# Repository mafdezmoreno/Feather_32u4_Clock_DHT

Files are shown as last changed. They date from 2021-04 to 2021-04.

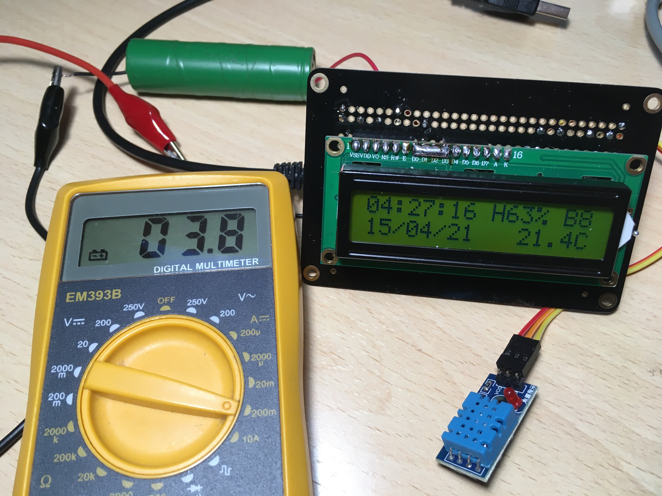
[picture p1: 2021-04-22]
low_power_demo.jpeg

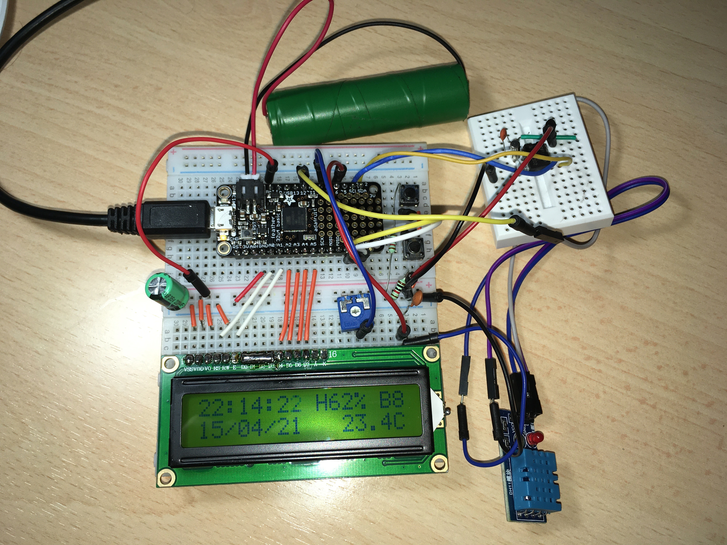
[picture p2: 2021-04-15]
clock_conections.jpeg

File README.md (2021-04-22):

# Feather_32u4_Clock_DHT
 RTC clock with liquid crystal display, humidity and temperature sensor, powered by lithium battery. Developed on a Feather 32u4 basic board.



## Initial Functional Version

Clock connected to RTC PCF8583.

__It is composed of__:

- Liquid crystal display
- Feather 32u4 basic
- Battery
- DHT11 sensor
- PCF8583

__Features__:

- Displays: time, date, battery level, temperature and humidity.
- Allows to change the time by push buttons

https://user-images.githubusercontent.com/59566401/114939320-90d66f80-9e40-11eb-9616-02955f184454.mp4

## New features. Low power consumption

Using the functions provided by the "avr/power.h" library, the average power consumption has been reduced to 3.8 mA. This allows powering the clock with a 3000mA battery for almost 30 days.

The power consumption reduction is achieved by deactivating the power supply to all the peripherals that are not necessary, and activating the necessary peripherals only during the strictly necessary time.

The following image shows the power consumption reduction achieved.

low_power_demo

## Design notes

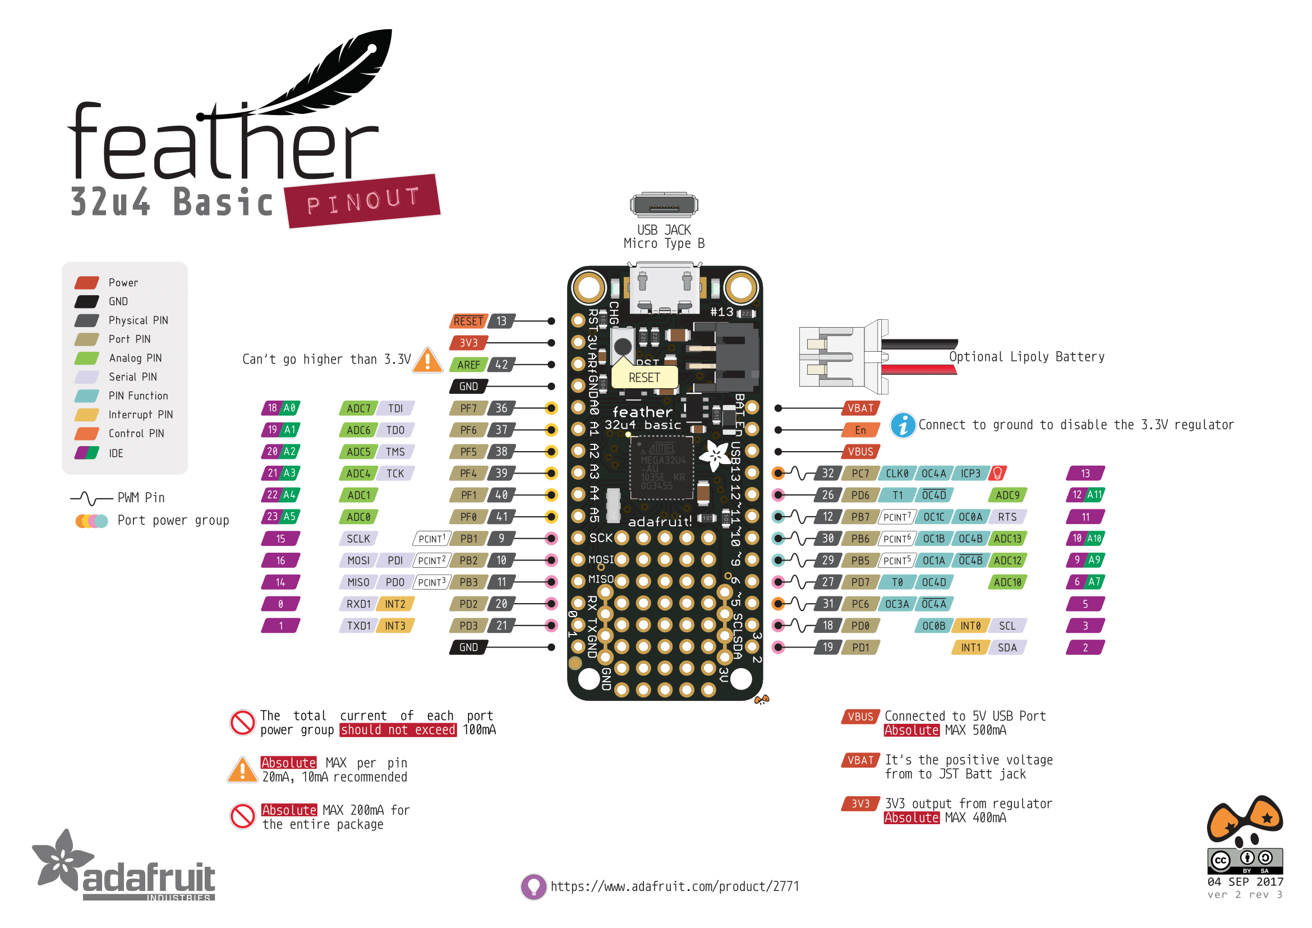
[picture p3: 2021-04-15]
Adafruit_Feather_32u4_Basic_Proto_v2.3-1.png

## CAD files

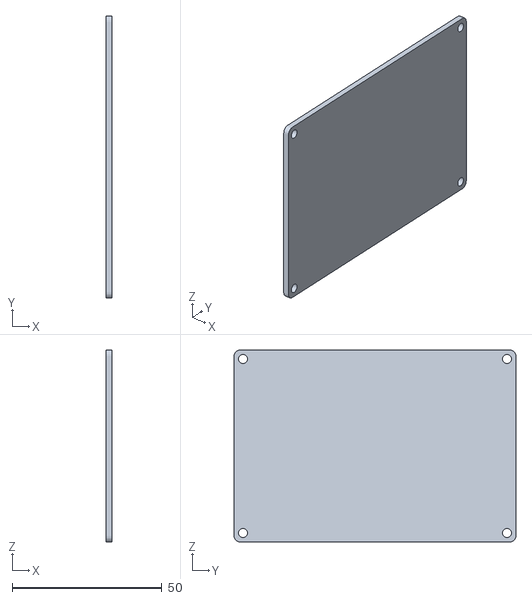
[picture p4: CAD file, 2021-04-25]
3D/PCB.stl
2.00 x 94.0 x 64.0

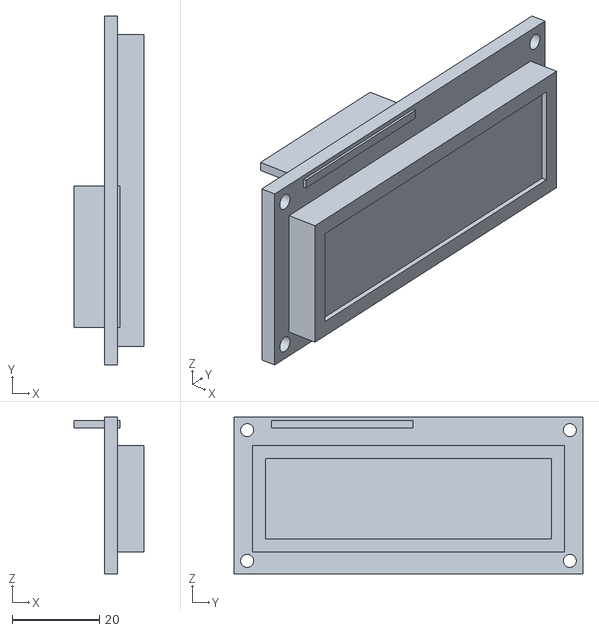
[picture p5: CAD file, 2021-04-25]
3D/LCD.stl
16.0 x 80.0 x 36.0

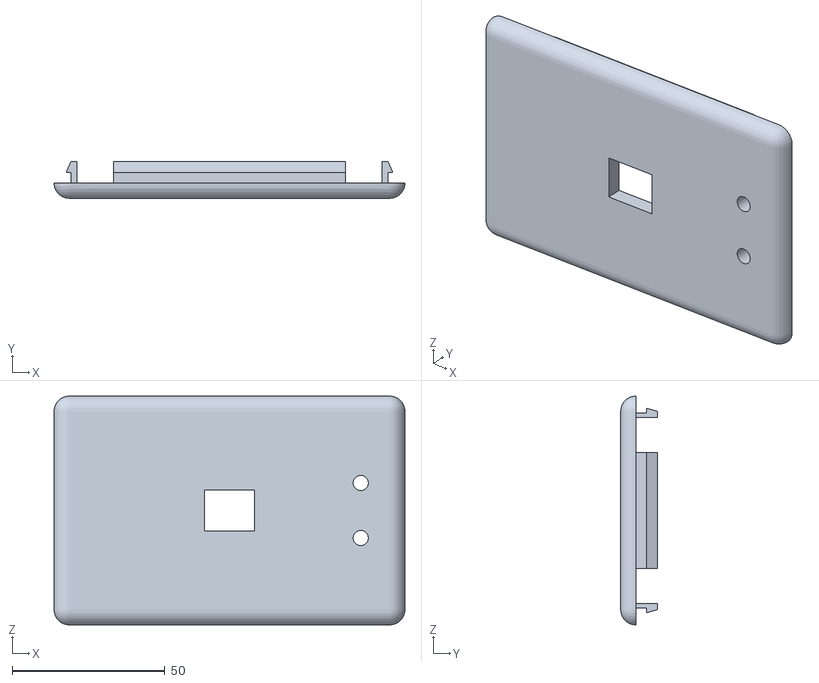
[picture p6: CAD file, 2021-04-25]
3D/Rear_Cover.stl
115.0 x 12.0 x 75.0

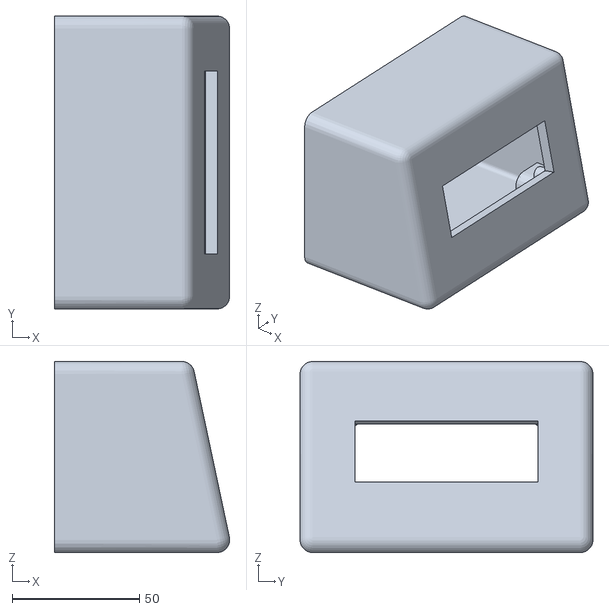
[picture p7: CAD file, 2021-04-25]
3D/Box.stl
68.8 x 115.0 x 75.0

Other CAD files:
3D/Box.prt
3D/Ensamblaje.prt
3D/LCD.prt
3D/PCB.prt
3D/Rear_Cover.prt

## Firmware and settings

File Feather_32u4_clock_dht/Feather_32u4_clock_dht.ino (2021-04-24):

/* Referencias:
https://www.mouser.es/datasheet/2/302/PCF8583-1127587.pdf
http://www.valachnet.cz/lvanek/diy/homebrain/index.html
https://bitbucket.org/xoseperez/pcf8583/src/master/
https://harizanov.com/2013/02/power-saving-techniques-on-the-atmega32u4/
https://www.nongnu.org/avr-libc/user-manual/group__avr__power.html
https://ww1.microchip.com/downloads/en/DeviceDoc/Atmel-7766-8-bit-AVR-ATmega16U4-32U4_Datasheet.pdf
*/
#include "LiquidCrystal.h"
#include "DHT.h"
#include "PCF8583.h"
#include <avr/power.h>

#define DHTPIN 9         // Pin digital
#define DHTTYPE DHT11     // Tipo sensor de humdad y temperatura
#define BAT_LEVEL_PIN A10 // Pin analógico monitorización batería
#define HORA_PIN 0
#define MIN_PIN 1
#define POWER_DHT 6       // Pin alimentación a sensor. Se activa 2 seg cada 30 seg, para ahorrar batería


// Inicialización de la pantalla LCD
const int rs = 19, en = 18, d4 = 20, d5 = 21, d6 = 22, d7 = 23;
LiquidCrystal lcd(rs, en, d4, d5, d6, d7);

// Inicialización de DHT
DHT dht(DHTPIN, DHTTYPE);

// Inicialización de RTC (Dirección I2C)
PCF8583 rtc(0xA0);

//Variables globales
unsigned int ano = 2021;
unsigned int mes = 4;
unsigned int dia = 22;
unsigned int hora = 23;
unsigned int min = 4;
unsigned int seg = 0;
unsigned int activacion_sensor = 243; //para no actualizar constantemente el sensor
                                //Para que me muestre la temp y humedad pronto pongo un valor cerca del valor de reinicio del contador (254)
unsigned int activacion_lect_nivel_bat = 990; //aprox 1000 seg (1000 loops)                               
bool imprimir_fecha = true;

void nivel_bateria();
void temperatura_humedad();
void setup();
void test_rtc(const char * test, byte expected, byte real);
void imprime_hora();
void cambiar_hora();
void imprime_fecha();
void low_power();
void blink_test();

void loop() {
  
  while (1){
    
    imprime_fecha();
    temperatura_humedad();
    nivel_bateria();
    imprime_hora();
    cambiar_hora();
    imprime_fecha();
    delay(998);
  }
}

void setup() {

  // E/S
  pinMode(POWER_DHT, OUTPUT);
  digitalWrite(POWER_DHT, LOW);
  pinMode(HORA_PIN, INPUT);
  pinMode(MIN_PIN, INPUT);

  //Configuración de la pantalla
  lcd.begin(16, 2); 
  lcd.print("Starting...");
  delay(500);
  lcd.setCursor(0, 1);

  // Configuración de RTC. Solo para comprobar correcto conexionado
  //rtc.setTime(0, 0, 0);
  //rtc.setDateTime(seg, min, hora, dia, mes, ano); //Descomentar para poner correctamente la serie
  //test_rtc("sec", 0, rtc.getSecond());

  //Configuración de DHT
  dht.begin();

  // Configuración para ahorrar batería
  low_power();
}

void low_power()
{
  ////////////////////////////////////////////
  //Se parte de un consumo inicial de 12.5mV
  ////////////////////////////////////////////
  delay(10000); //para permitir resetear y cargar nuevo firmware
  // Se desactivan periféricos que no se usan del micro
  power_adc_disable(); //Hace que no funcione la lectura analógica del nivel de batería
  //power_aca_enable(); // Se activa solo temporalmente para leer el nivel de batería
  power_usart1_disable();
  power_usart0_disable();
  power_timer1_disable();  
  power_timer2_disable();
  power_timer3_disable();
  power_spi_disable();
  power_usb_disable();
  //power_twi_disable(); //NO USAR Hace que no funcione la pantalla LCD
  ////////////////////////////////////////////
  // Hasta aquí, se consiguen 11mA de consumo
  ////////////////////////////////////////////
  lcd.clear();
  lcd.print("Setting RC ON"); 
  delay(500);

  // Switch to RC Clock 
  UDINT  &= ~(1 << SUSPI); // UDINT.SUSPI = 0; Usb_ack_suspend
  USBCON |= ( 1 <<FRZCLK); // USBCON.FRZCLK = 1; Usb_freeze_clock
  PLLCSR &= ~(1 << PLLE); // PLLCSR.PLLE = 0; Disable_pll
 
  CLKSEL0 |= (1 << RCE); // CLKSEL0.RCE = 1; Enable_RC_clock()
  while ( (CLKSTA & (1 << RCON)) == 0){}    // while (CLKSTA.RCON != 1);  while (!RC_clock_ready())
  CLKSEL0 &= ~(1 << CLKS);  // CLKSEL0.CLKS = 0; Select_RC_clock()
  CLKSEL0 &= ~(1 << EXTE);  // CLKSEL0.EXTE = 0; Disable_external_clock
  
  lcd.clear();
  lcd.print("RC ON"); 
  delay(1000);

  ////////////////////////////////////////////
  // Hasta aquí, se consiguen 7.8mA de consumo
  ////////////////////////////////////////////

  clock_prescale_set(clock_div_4); // Reduce el consumo hasta 5,6mA, pero no funciona el sensor DHT
                                   // Cambiar a "clock_div_1" cuando se tenga que leer el sensor DHT y justo despues volver a "clock_div_2" para ahorrar energía


  ////////////////////////////////////////////
  // Consumo final conseguido: 
  /////                      5.4mA de consumo con "clock_div_2"
  /////                      3.8mA de consumo con "clock_div_4""
  ////////////////////////////////////////////

  lcd.clear();
  lcd.print("Low Power ON"); 
  delay(1000);
  //blink_test();
  lcd.clear();

}

void cambiar_hora(){
  while (digitalRead(MIN_PIN)){
    
    delay(50);
    if (digitalRead(MIN_PIN)){
        if (++min > 59){
          min = 0;
        }
        rtc.setTime(seg, min, hora);
    }
    imprime_hora();
    delay(400); 
  }

  while (digitalRead(HORA_PIN)){
    delay(50);
    if (digitalRead(HORA_PIN)){
        if (++hora > 23){
          hora = 0;
        }
        rtc.setTime(seg, min, hora);
    }
    imprime_hora();
    delay(400);
  }

}

void imprime_hora(){
    lcd.setCursor(0, 0);
    //Hora
    hora = rtc.getHour();
    if (hora<10){
      lcd.print(0);
    }
    lcd.print(hora);
    lcd.print(":");
    //Minuto
    min = rtc.getMinute();
    if (min<10){
      lcd.print(0);
    }
    lcd.print(min);
    lcd.print(":");
    //Segundo
    seg = rtc.getSecond();
    if (seg<10){
      lcd.print(0);
    }
    lcd.print(seg);

}

void test_rtc(const char * test, byte expected, byte real) {
    lcd.clear();
    lcd.setCursor(0, 1); // segunda fila, posición 0
    if (expected == real) {
        lcd.print("OK");
        lcd.print(real);

    } else {
        lcd.print("KO");
        lcd.print(test);
        delay(500);
        abort();
    }
}
void temperatura_humedad(){

  if (activacion_sensor == 245){
    digitalWrite(POWER_DHT, HIGH);
    clock_prescale_set(clock_div_1);
  }
  else if (activacion_sensor == 250){  
    int h = dht.readHumidity();
    float t = dht.readTemperature();
    digitalWrite(POWER_DHT, LOW);
    lcd.setCursor(11, 1); // segunda fila, posición 11

    // Si la lectura no es correcta, imprime fallo
    if (isnan(h) || isnan(t)) {
      lcd.print("Fallo");
    }
    else{
      //Imprime temperatura
      lcd.print(t,1);
      lcd.print("C");
      
      lcd.setCursor(9, 0);
      lcd.print("H");
      lcd.print(h);
      lcd.print("%");
    }
    activacion_sensor = 0;
    clock_prescale_set(clock_div_4);
  } 
    activacion_sensor ++;
}

void nivel_bateria(){
    
    if (activacion_lect_nivel_bat == 995){
      power_adc_enable();
    }
    else if(activacion_lect_nivel_bat == 1000){
      int bat_level = 0;
      int bat_level_maped = 0;
      bat_level = analogRead(BAT_LEVEL_PIN); //El nivel real está dividido entre 2 
      bat_level_maped = map(bat_level*2, 930, 1240, 0, 9); 
                          //1240 equivale a 4 volt
                          //930 equivale a 3 volt (batería gastada)
      lcd.setCursor(14, 0);
      lcd.print("B");
      lcd.print(bat_level_maped);
      lcd.print(bat_level);
      activacion_lect_nivel_bat = 0;
      power_adc_disable();      
    }
  activacion_lect_nivel_bat++;      
}

void imprime_fecha(){

  if ((hora == 0)&&(min == 0)&&(seg<5)){
    imprimir_fecha = true;
  }

  if (imprimir_fecha){
    lcd.setCursor(0,1);
    int day = rtc.getDay();
    if (day<10){
      lcd.print("0");
    }
    lcd.print(day);
    lcd.print("/");

    int mes = rtc.getMonth();
    if (mes<10){
      lcd.print("0");
    }
    lcd.print(rtc.getMonth());
    lcd.print("/");
    
    lcd.print(rtc.getYear()%2000);
    
    imprimir_fecha = false;
  }
}


void blink_test(){

  pinMode(13,OUTPUT); 
  for(int i=0;i<10;i++){
    digitalWrite(13,HIGH);
    delay(100);
    digitalWrite(13,LOW);
    delay(100);
  } 
}

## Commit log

2021-04-15 Initial Functional Version
    Clock connected to RTC PCF8583. It is composed of:
    Liquid crystal display
    Feather 32u4 basic
    Battery
    DHT11 sensor
    Features:
    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
2021-04-18 Fritzing schematic
    [Esquema.fzz]
2021-04-20 Compact Proto PCB Design
2021-04-22 Cambios en esquema para facilitar conexionado Protoboard
    [Esquema.fzz, Esquema_compacto.fzz]
2021-04-22 Low power feature doc
2021-04-22 Low power added and tested
2021-04-25 Working in 3D models
    [Box.prt, Electornic_Assembly.prt, LCD.prt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]
2021-04-25 3D models
    [Box.prt, Box.stl, Electornic_Assembly.prt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]
